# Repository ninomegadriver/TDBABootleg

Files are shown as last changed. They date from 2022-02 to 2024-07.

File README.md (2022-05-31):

# Taito do Brasil Arcade Bootleg  
**Jamma arcade board based on the original "Fantastic" hardware by Taito do Brasil**  
Nino MegaDriver - nino@nino.com.br  
License GPL v3.0  
***************** 
## Main Features  

- ESP32 Wroom Devkit V1 which functions as CPU and graphics generator.  
- Two AY-3-9010 PSGs
- Serial data bus with three Atmega328p to handle controller inputs and driving the PSGs.  
- Audio mixing between PSGs and 2 DACs which can be activated via dip switches.    
  
**Actual Board Picture:**  
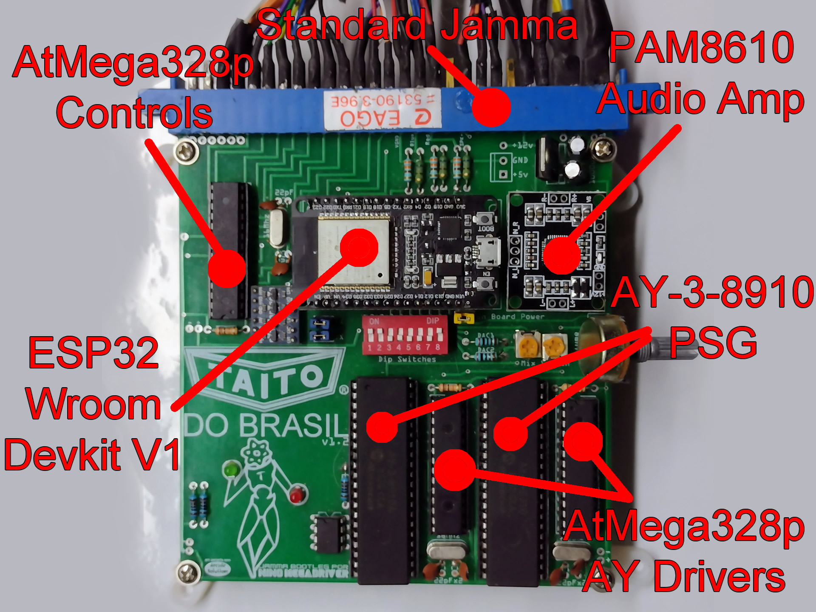
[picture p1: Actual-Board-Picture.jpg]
acual board picture
  
  
*****************
## PCB Gerbers  
**The board is released as "open hardware" under the GPL 3.0.  
[Gerbers for production is available here.](https://github.com/ninomegadriver/TDBABootleg/tree/main/PCB_Gerbers)**  
  
**PCB Footprints:**  
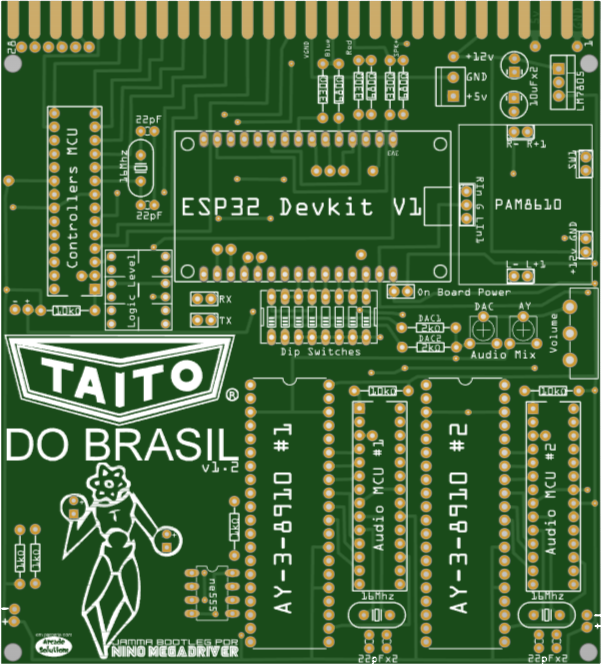
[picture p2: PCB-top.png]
PCB Top
  
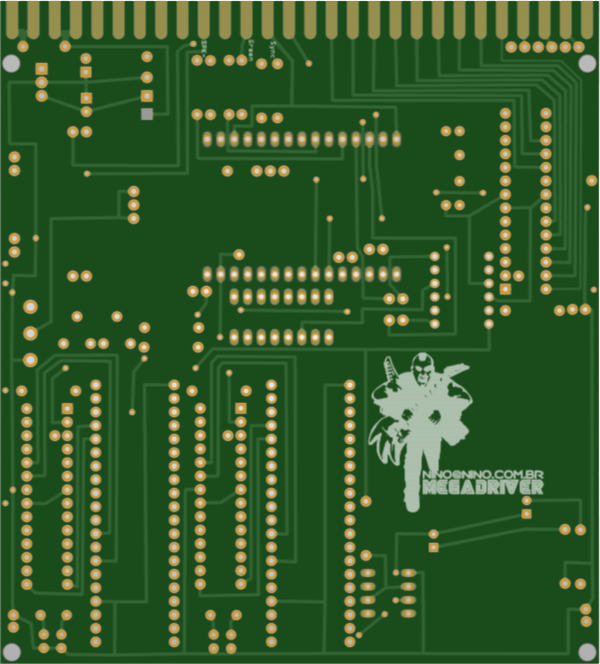
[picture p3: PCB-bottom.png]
PCB Bottom
  
  
***************
## Serial Protocol  
  
This project uses standard UART serial protocol at 115200 baud rate. One Atmega328p is used to poll player inputs and sends the data over serial. Two Atmega328p listens on serial for instructions to drive its own AY-3-8910 PSG.  

The controllers MCU sends two bytes, one for each player as follows:  
```
  0b00000001 => COIN;
  0b00000010 =>  START;
  0b00000100 =>  UP;
  0b00001000 =>  DOWN;
  0b00010000 =>  LEFT;
  0b00100000 =>  RIGHT;
  0b01000000 =>  BT1;
  0b10000000 =>  BT2;
```  
  
Each AY-3-8910 Atmega328p drivers has it's own #id hardcoded, data is sent as three bytes structured as:  
```
struct YMREG{
  uint8_t chip;
  uint8_t reg;
  uint8_t data;
  bool dirty = false;
};
(...)
      buf[0] = YMBUFF[ym_flush_pos].chip;
      buf[1] = YMBUFF[ym_flush_pos].reg;
      buf[2] = YMBUFF[ym_flush_pos].data;
      Serial.write(buf, 3);
      Serial.flush();
(...)
```  
The data is always received by the two drivers, but it's is only processed if it's flagged with its #id.  
  
***************************
## Supported Games  
  
This project was initially focused on the "Fantastic", an arcade "Galaxian" licensed game clone, developed by Taito do Brasil in 1981. It all started as a couple of spare boards donated to me. Later on, an original rack came in my shop for repair, providing me a real hardware to use as source of actual information. So, the initial goal was to run a Z80 emulator on an ESP32 but using original hardware for audio, the same configuration used on the Fantastic racks.  
  
As of today, we have the following fully playable games:  
- Fantastic, 1981.  
- Gorila, 1981.  
  
**See it in action here:**  
Taito Do Brasil Bootleg v1.2 - Fantastic Hardware (https://www.youtube.com/watch?v=sqsus4Gnz_k)  
  
The ESP32 should be powerful enough to run many more classic and single processed arcade games. A work-in-progress is ongoing for supporting more Taito do Brasil games that run on Space Invaders hardware, such as:  
  
- Galactica - Batalha Espacial.
- Indian Battle.
- Space Invaders.
- Space Invaders Part II.
- Polaris.
  
**Work-in-progress of the Invaders hardware here:**  
Taito Do Brasil Bootleg v1.2 - Invaders Hardware (WIP) (https://www.youtube.com/watch?v=LioPVbTkof8)  

***************************
## Special Thanks  
  
- Tom Walker and his emulator YAAME (http://yaame.emuunlim.com/) which served as a base for the graphics routines used in the [ESP32_HW_Fantastic](https://github.com/ninomegadriver/TDBABootleg/tree/main/ESP32_HW_Fantastic) code.
- Alessandro Scotti for his fast an reliable [Space Invaders emulator](https://walkofmind.com/programming/side/side.htm) which provided most of the routines used in the [ESP32_HW_Invaders](https://github.com/ninomegadriver/TDBABootleg/tree/main/ESP32_HW_Invaders) code.
- All MAME developers for providing tons of references and info in the MAME sources.  
- Fabrizio Di Vittorio for his amazing FabGL graphics library which made the video implementation in project really easy.  
- Alexsander dos Santos, which kindly donated a few Fantastic PCBs that served as a sparkling for this project. 
- Luis Culik from the "Museu do Pinball de Itu" for entrusting me a very rare and unique original Fantastic rack for repair, which also served as source of information on the actual original hardware.  
- Emerson de Holanda from "Arcade Solutions" for overall supporting the project.    
  
***************************
Comments, suggestions, support and help are always welcome.  
Wanna join in or just chat?  
You can reach me at:  
nino@nino.com.br  
[Facebook "ninomegadriver"](https://facebook.com/ninomegadriver)

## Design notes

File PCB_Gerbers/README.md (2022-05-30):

# "Taito do Brasil Arcade Bootleg v1.2" PCB  
## Gerbers provided as "open hardware" under the terms of GPL v3.0.  
  
PCB Top  
PCB Bottom  
  
**Bill Of Materials:**  
[Taito_do_Brasil_Arcade_Bootleg_v1.2_bom.html](https://github.com/ninomegadriver/TDBABootleg/blob/main/PCB_Gerbers/Taito_do_Brasil_Arcade_Bootleg_v1.2_bom.html)

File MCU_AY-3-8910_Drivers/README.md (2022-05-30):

# TDBABootleg: AY-3-8910 Drivers MCU  
Bin image for the ATmega328p used for driving the AY-3-8910 PSGs  
  
*****************************************
CHIP #1:  
  
Binary image:  
[MCU_AY-3-8910_AtMega328p-CHIP1.bin](https://github.com/ninomegadriver/TDBABootleg/raw/main/MCU_AY-3-8910_Drivers/MCU_AY-3-8910_AtMega328p-CHIP1.bin)  
  
Fuse configuration:  
Low byte: 0xFF  
High byte: 0xDE  
Extended: 0xFD  
Lock Byte: 0xCF  
  
Fuse reference screenshot:  
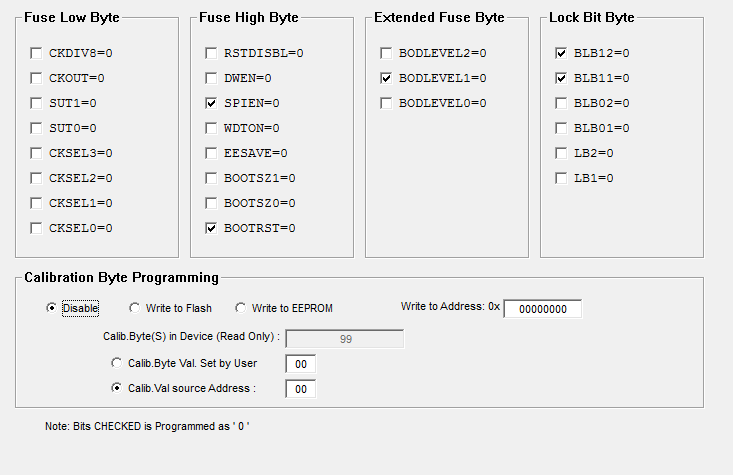
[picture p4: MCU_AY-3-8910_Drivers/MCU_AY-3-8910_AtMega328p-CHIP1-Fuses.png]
Atmega328p %1
  
  
****************************************  
CHIP #2:  
  
Binary dump:  
[MCU_AY-3-8910_AtMega328p-CHIP2.bin](https://github.com/ninomegadriver/TDBABootleg/raw/main/MCU_AY-3-8910_Drivers/MCU_AY-3-8910_AtMega328p-CHIP2.bin)  
  
Fuse configuration:  
Low byte: 0xFF  
High byte: 0xDE  
Extended: 0xFD  
Lock Byte: 0xFF  
  
Fuse reference screenshot:  
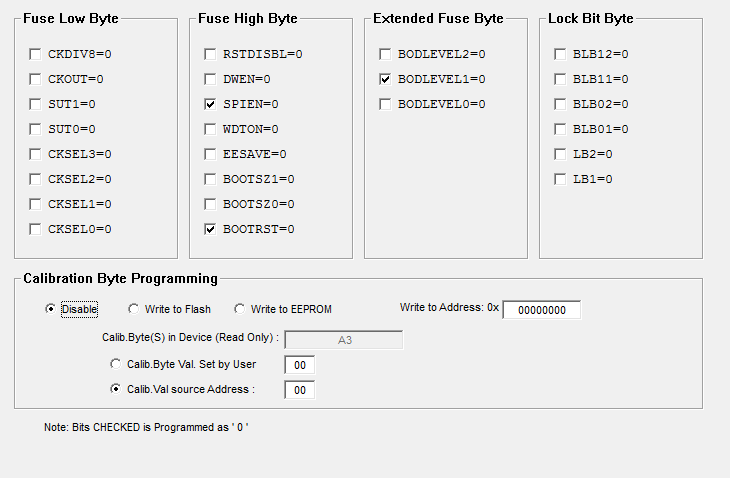
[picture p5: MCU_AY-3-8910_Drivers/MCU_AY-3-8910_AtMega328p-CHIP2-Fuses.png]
Atmega328p %1


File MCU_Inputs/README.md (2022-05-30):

# TDBABootleg: Player Inputs MCU  
Bin image for the ATmega328p used for handling the player inputs over jamma.  
  
Binary dump file:
[MCU_Inputs-ATMEGA328P.bin](https://github.com/ninomegadriver/TDBABootleg/raw/main/MCU_Inputs/MCU_Inputs-ATMEGA328P.bin)

Fuse configuration:  
Low byte: 0xFF  
High byte: 0xDE  
Extended: 0xFD  
Lock Byte: 0xFF  
  
Fuse reference configuration:  
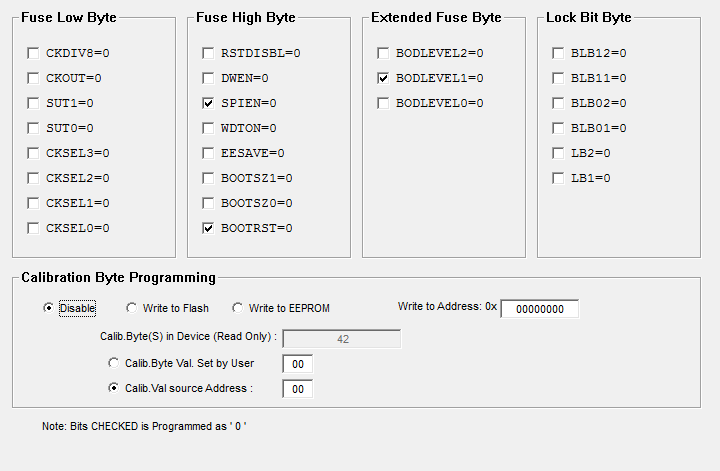
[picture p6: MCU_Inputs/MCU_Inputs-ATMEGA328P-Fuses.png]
Fuses Input MCU


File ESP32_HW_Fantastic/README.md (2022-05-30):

# TDBABootleg: Main code for the "FANTASTIC" Hardware  
  
Taito do Brasil Arcade Bootleg v1.2  
Nino MegaDriver - nino@nino.com.br  
License GPL v3.0  
  
Maincode for the ESP32 Devkit V1 module. Code based on the "FANTASTIC" arcade board manufactured by Taito do Brasil, which was itself based on the original Galaxian rack by Namco.  
  
Currently fully playable games:  
  
- Fantastic
- Gorila

Libraries used:  
  
- FabGL (http://www.fabglib.org/) for video generation.  
- DacAudio by https://www.xtronical.com/  
- Z80 emulator from Lin Ke-Fong.  
  
Special Thanks:  
  
- Tom Walker and his emulator YAAME (http://yaame.emuunlim.com/) which served as a base for the graphics routines used in this code.
- All MAME developers for providing tons of references and info in the MAME sources.  
- Fabrizio Di Vittorio for his amazing FabGL graphics library which made the video implementation in project really easy.  
- Alexsander dos Santos, which kindly donated a few Fantastic PCBs that served as a sparkling for this project. 
- Luis Culik from the "Museu do Pinball de Itu" for entrusting me a very rare and unique original Fantastic rack for repair, which also served as source of information on the actual original hardware.  
- Emerson de Holanda from "Arcade Solutions" for overall testing and supporting the project.  
  
Building Instructions:  
  
Download and install FabGL into your Arduino IDE and load the project. I strongly recommend modifying all FabGL sources to use the GCC "-O3" optimization flag as it will result on a huge increase of performance. On Linuxes, one suggestion is to enter the $/Arduino/libraries/FabGL folder and use "sed" to replace "-O2" with "-O3" like this:   
  
```
for i in `find -name "*.cpp"`; do sed -i 's/"O2"/"O3"/g' $i; done;
```  
  
I also recommend using this [sdkconfig](https://raw.githubusercontent.com/ninomegadriver/TDBABootleg/main/ESP32_HW_Fantastic/sdkconfig) with optimal settings for this project.  

See it in action here:  
Taito Do Brasil Bootleg v1.2 - Fantastic Hardware (https://www.youtube.com/watch?v=sqsus4Gnz_k)

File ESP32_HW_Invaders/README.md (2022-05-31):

# TDBABootleg: Main code for the "INVADERS" Hardware  
  
Taito do Brasil Arcade Bootleg v1.2  
Nino MegaDriver - nino@nino.com.br  
License GPL v3.0  
  
Maincode for the ESP32 Devkit V1 module. Code based on the "Space Invaders" arcade board manufactured by Taito do Brasil  
  
Most of this code was ported from the very fast and reliable emulator
["SIDE - Space Invaders Didactic Emulator"](https://walkofmind.com/programming/side/side.htm) by Alessandro Scotti.  
  
This is still in a work-in-progress state. However we have this currently playable games:  
  
- Galactica - Batalha Espacial.
- Indian Battle.
- Space Invaders.
- Space Invaders Part II.
- Polaris
  
Libraries used:  
  
- FabGL (http://www.fabglib.org/) for video generation.  
- DacAudio by https://www.xtronical.com/  
  
Special Thanks:  
  
- Alessandro Scotti for his fast an reliable Space Invaders emulator which provided most of the routines used here.
- All MAME developers for providing tons of references and info in the MAME sources.  
- Fabrizio Di Vittorio for his amazing FabGL graphics library which made the video implementation in project really easy.  
- Emerson de Holanda from "Arcade Solutions" for overall testing and supporting the project.  
  
Building Instructions:  
  
I strogly recommend using this [sdkconfig](https://raw.githubusercontent.com/ninomegadriver/TDBABootleg/main/ESP32_HW_Fantastic/sdkconfig) with optimal settings for this project.  

See a WIP video here:  
Taito Do Brasil Bootleg v1.2 - Invaders Hardware (WIP) (https://www.youtube.com/watch?v=LioPVbTkof8)

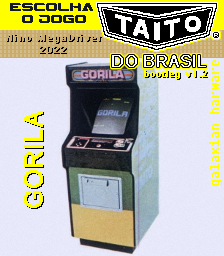
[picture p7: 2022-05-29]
ESP32_HW_Fantastic/resources/catalog.fw.png

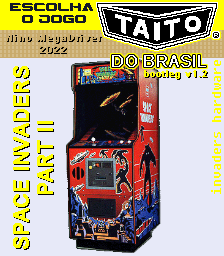
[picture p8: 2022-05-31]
ESP32_HW_Invaders/resources/catalog.fw.png

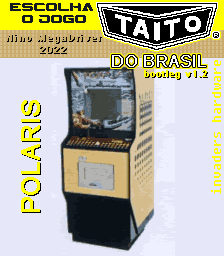
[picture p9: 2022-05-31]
ESP32_HW_Invaders/resources/bkp/menu_polaris.png

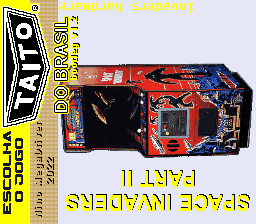
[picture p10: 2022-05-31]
ESP32_HW_Invaders/resources/menu_invaders2.png

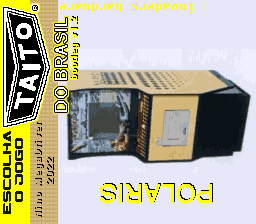
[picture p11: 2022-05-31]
ESP32_HW_Invaders/resources/menu_polaris.png

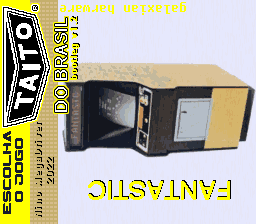
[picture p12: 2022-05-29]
ESP32_HW_Fantastic/resources/menu_fantastc.png

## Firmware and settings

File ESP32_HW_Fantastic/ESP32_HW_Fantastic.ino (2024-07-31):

#pragma GCC optimize ("O3")

/*
 * Taito do Brasil Arcade Bootleg v1.2
 * Nino MegaDriver - nino@nino.com.br
 * License GPL v3.0
 * 
 * Maincode for the ESP32 Devkit V1 module
 * Code based on the "FANTASTIC" arcade board
 * 
 * Libraries and Helpers used:
 * 
 * FabGL (http://www.fabglib.org/) for video generation
 * DacAudio by https://www.xtronical.com/
 * Z80 emulator code derived from Lin Ke-Fong
 * Graphics routines derived from YAAME by Tom Walker (http://yaame.emuunlim.com/)
 * +Tons of references and info taken from MAME sources
 * 
 */

// TIMER Helpers - used in Serial Tasks
#include "soc/timer_group_struct.h"
#include "soc/timer_group_reg.h"

// Usually sprite priority would not be needed as long as we
// clear the screen prior to start drawing on it. However we're not
// fast enought to fill the whole screen each frame, nor do we
// have enough RAM to use double buffering. So to avoid
// blinking sprites, we need to implement a priority system so
// not to draw the same pixel twice.
//
// Althought a boolean variable suggests that only one bit is
// necessary to store it, it is surprisingly stored as one whole byte!
//
// Then, if you think of a 256x256 pixels wide screen, it would
// take 65kb of RAM to store it into a variable and we obviously can't
// afford that... 
//
// However, if we treat each pixel as a single bit instead
// of one byte, the amount of RAM would go down to just 8k!
// 

byte objdirty[8192]; // 8192 bytes = 256*256/8, more then enought for us...
uint8_t busy = 0; // Semaphore for Video Drawing

// Core Configuration
int cpuCore  = 1; // Core # for CPU
int gfxCore  = 0; // Core # for GPU

// Bitwise heler functions defines
#define BITS_PER_BYTE (8)
#define GET_BIT(x, n) ((((x)[(n) / BITS_PER_BYTE]) & (0x1 << ((n) % BITS_PER_BYTE))) != 0)
#define SET_BIT(x, n) ((x)[(n) / BITS_PER_BYTE]) |= (0x1 << ((n) % BITS_PER_BYTE))
#define RESET_BIT(x, n) ((x)[(n) / BITS_PER_BYTE]) &= ~(0x1 << ((n) % BITS_PER_BYTE))

// Set a pixel at given position dirty
void set_dirty(int x, int y){
  int pixel = x * 256 + y;
  SET_BIT(objdirty,pixel);
}

// Reset dirty state of a pixel at given position
void reset_dirty(int x, int y){
  int pixel = x * 256 + y;
  RESET_BIT(objdirty,pixel);
}


// Return if pixel at given position is dirty
int get_dirty(int x, int y){
  int pixel = x * 256 + y;
  return GET_BIT(objdirty,pixel);
}

// Basic structure for transfering AY-3-8910
// register values over Serial
struct YMREG{
  uint8_t chip;
  uint8_t reg;
  uint8_t data;
  bool dirty = false;
};
#define YMBUFFSIZE 200                            // AY-3-8910 serial buffer transfer value
YMREG YMBUFF[YMBUFFSIZE];                         // AY-3-8910 buffer
uint8_t ym_flush_pos = 0;                         // AY-3-8910 flush position
uint8_t ym_write_pos = 0;                         // AY-3-8910 write position

#include "fabgl.h"                                // Main FabGL include
#include "machine.h"                              // Z80 Machine object
#include "res.hpp"

uint8_t player1_ctl = 0x00;                       // Byte containing the players buffer
uint8_t player2_ctl = 0x00;                       // One bit for each input

int GAME = 7;                                     // What game are we running today? See numbering bellow...


// INPUT BITS for each game supported
// Currently only Fantastic and Kong/Gorila are fully playable
//
// Game                            [Fantastic], [Kong], [Time Fighters], [Super Star Crest], [Zig Zag], [Galaxian Taito], [Munch Man], [Galaxy Empire]
// Index                                0         1            2                3                 4            5               6              7
uint8_t IPT_COIN1[] =           {     0x02,     0x02,        0x02,             0x01,            0x01,         0x02,           0x02,         0x02,  };
uint8_t IPT_JOYSTICK_LEFT[] =   {     0x04,     0x04,        0x04,             0x04,            0x04,         0x04,           0x04,         0x02,  };
uint8_t IPT_JOYSTICK_RIGHT[] =  {     0x08,     0x08,        0x08,             0x08,            0x08,         0x08,           0x08,         0x02,  };
uint8_t IPT_JOYSTICK_UP[] =     {     0x07,     0x80,        0x80,             0x07,            0x20,         0x07,           0x40,         0x02,  };
uint8_t IPT_JOYSTICK_DOWN[] =   {     0x07,     0x20,        0x20,             0x07,            0x40,         0x07,           0x80,         0x02,  };
uint8_t IPT_BUTTON1[] =         {     0x10,     0x07,        0x10,             0x10,            0x10,         0x10,           0x10,         0x02,  };
uint8_t IPT_START1[] =          {     0x01,     0x01,        0x01,             0x01,            0x01,         0x01,           0x01,         0x02,  };
uint8_t IPT_START2[] =          {     0x02,     0x02,        0x02,             0x02,            0x02,         0x02,           0x02,         0x02,  };

// Frame Duration time.
// Tune in if you want more fps
uint64_t frame_time[] =         {     14000,     140000,       14000,            14000,           14000,         14000,        14000,       14000   };

int nmi = 0;                                      // MNI Helper, 1 when MNI is pending

fabgl::VGAController  DisplayController;          // Main Video Object
fabgl::Canvas cv(&DisplayController);

Machine              fantastc;                    // Main CPU machine object

#include "XT_DAC_Audio.h"                         // DacAudio main include
XT_DAC_Audio_Class DacAudio(25,0);                // Main Class, using GPIO25 as PCM generator
int voice_playing[] = {0, 0, 0, 0, 0, 0 , 0};     // Helper for controlling voice samples
long voice_latch = 0;                             // Latch for voice samples

int screen_width   = 0;                           // Main output screen width, overwrited on setup();
int screen_height  = 0;                           // Main output screen height, overwrited on setup();

bool wireframe     = false;                       // Draw wireframe to display screen bounds?

uint8_t pixel[32];                                // R/W array of "pixels with defined color", used as the color palette
#include "fantastc.hpp"                           // "FANTASTIC" game includes
#include "kong.hpp"                               // "GORILA" (a.k.a "kong") game includes
#include "timefgtr.hpp"                           // "TIME FIGHTER" game includes
#include "sstarcrs.hpp"                           // "SUPER STAR CREST" game includes
#include "zigzag.hpp"                             // "ZIG ZAG" game includes
#include "samples.hpp"                            // PCM samples used by "GORILA"
#include "munch.hpp"                              // "Munch Man" game includes
#include "galaxiant.hpp"                          // "Galaxian Title" game includes"
#include "galemp.hpp"

// Menuing Vars
Bitmap *menu_bitmaps[] = { &menu_fantastc, &menu_kong};                 // Bitmaps for the selection page for each game
XT_Wav_Class *menu_samples[] = {&wav_menu_fantastic, &wav_menu_gorila}; // Samples for each menu page
uint8_t menu_active = 0;                                                // Menu active?
int menu_item = GAME;                                                   // Default menu item pointing to default GAME
uint8_t menu_item_last = -1;                                            // Last selected item
uint8_t menu_item_max = 1;                                              // Max index for the menu items (Currently only Fantastic and Kong are playable


// Direct sets a pixel on the output screen buffer
bool setpixel(int x=0, int y=0, int idx=0 , int force = 0){

    if(get_dirty(x, y) && force == 0) {
      reset_dirty(x, y);
      return false; // If pixel is dirty/already drawn, skip it!
    }

    if(idx>31) idx=0;
    int dx = screen_width-y-1;
    int dy = x;

    dx-=32;
    dy-=16;
    if(dx<32 || dx > 288 || dy<3 || dy > screen_height-2) return false;

    // Let's fix the orientation again to match original hardware
    dx = screen_width  - dx;
    dy = screen_height - dy;
    

    if(dx < screen_width && dy <screen_height && dx>= 0 && dy >= 0){
        DisplayController.setRawPixel(dx,dy,pixel[idx]);
        return true;
    }else{
       return false;
    }
}

// Very ugly but somehow needled.
// Using pointers to complex arrays panics or slows the esp32 core
int tileval(int c, int x, int y){
  if(GAME == 0) return fantastc_tiles[c][x][y];
  if(GAME == 1) return kong_tiles[c][x][y];
  if(GAME == 2) return timefgtr_tiles[c][x][y];
  if(GAME == 3) return crest_tiles[c][x][y];
  if(GAME == 4) return zigzag_tiles[c][x][y];
  if(GAME == 5) return galaxiant_tiles[c][x][y];
  if(GAME == 6) return munch_tiles[c][x][y];
  if(GAME == 7) return galemp_tiles[c][x][y];
  return 0;
}

// Helper, prints a tile on screen
// Using for debugging
void tilep(int t, int xx, int yy, int tint=0, int xflip=0, int yflip=0, int bits=0){
  int idx;
  for(int x=0;x<8;x++){
    for(int y=0;y<8;y++){
      idx =  tileval(t,x,y);
      setpixel(x+xx, y+yy, idx);
    }
  }
}

// Helper, prints all tiles on screen
// Using for debugging
void dumptiles(){
  int xx = 0;
  int yy = 0;
  for(int c=0; c<512; c++)
  {
    tilep(c, xx, yy);
    xx+=10;
    if(xx>256){
      xx = 0;
      yy+=10;
      if(yy>256){
        yy = 0;
      }
    }
  }  
}


// Code derived from YAAME by Tom Walker (http://yaame.emuunlim.com/)
// Draws a decoded tile on screen
void drawtilenew(int tile, int x, int y, int col, int xflip, int yflip, int bits)
{

        int xx,yy, idx;
        if (!yflip)
        {
               if (!xflip)
               {
                        for (yy=0;yy<8;yy++)
                            for (xx=0;xx<8;xx++){
                                  idx = tileval(tile,xx,yy)|(col<<bits);
                                  setpixel(x+xx, y+yy, idx);
                            }
                                
               }
               else
               {
                        for (yy=0;yy<8;yy++)
                            for (xx=0;xx<8;xx++){
                                  idx = tileval(tile,7-xx,yy)|(col<<bits);
                                  setpixel(x+xx, y+yy, idx);
                            }
               
               }
        }
        else
        {
               if (!xflip)
               {
                        for (yy=0;yy<8;yy++)
                            for (xx=0;xx<8;xx++){
                                  idx = tileval(tile,xx,7-yy)|(col<<bits);
                                  setpixel(x+xx, y+yy, idx);
                            }
                                
               }
               else
               {
                        for (yy=0;yy<8;yy++)
                            for (xx=0;xx<8;xx++){
                                  idx = tileval(tile,7-xx,7-yy)|(col<<bits);
                                  setpixel(x+xx, y+yy, idx);
                            }
                                
               }
        }
}
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
void loop() {
  cpuCore = xPortGetCoreID();
  if(cpuCore == 1) gfxCore = 0;
  else gfxCore = 1;
  load_game(GAME);
}


/*
 * Z80 Machine Declarations
 */
Machine::Machine()
  : m_realSpeed(false)
{
  m_Z80.setCallbacks(this, readByte, writeByte, readWord, writeWord, readIO, writeIO);
}

Machine::~Machine()
{
  delete [] m_RAM;
}

// Title screen includes substitution for "GORILLA"
#include "gorila_title.hpp"                       

bool chkSprite(int x, int y){
  int spritex,spritey,cc,ccc;
  for (cc=14;cc>-1;cc--){
    ccc=cc<<2;
    spritex=fantastc.m_RAM[0x9840+ccc]+8;
    if (spritex>8 && spritex<0xF8){
      spritey=fantastc.m_RAM[0x9843+ccc]+1;
      if(x == spritex && y == spritey) return false;
      else return true;
    }
  }
}

void drawBullets(const uint8_t *base){
  int dx, dy;
  int m_flipscreen_y = 0;
  /* iterate over scanlines */
  for (int y = 0; y <= 224; y++)
  {
    uint8_t shell = 0xff, missile = 0xff;
    uint8_t effy;

    /* the first 3 entries match Y-1 */
    effy = m_flipscreen_y ? ((y - 1) ^ 255) : (y - 1);
    for (int which = 0; which < 3; which++)
      if (uint8_t(base[which*4+1] + effy) == 0xff)
        shell = which;

    /* remaining entries match Y */
    effy = m_flipscreen_y ? (y ^ 255) : y;
    for (int which = 3; which < 8; which++)
      if (uint8_t(base[which*4+1] + effy) == 0xff)
      {
        if (which != 7)
          shell = which;
        else
          missile = which;
      }
    
    /* draw the shell */
    if (shell != 0xff) {
      dy = 224 - base[shell*4+3] + 24 ;
      dx = 255 -y + 8;
      setpixel(dx, dy,   3, 32);
      setpixel(dx, dy+1, 3, 32);
      setpixel(dx, dy+2, 3, 32);
    }

    if (missile != 0xff){
      dy = 224 - base[missile*4+3] + 24;
      dx = 255 -y + 8;
      setpixel(dx, dy,   3, 1);
      setpixel(dx, dy+1, 3, 1);
      setpixel(dx, dy+2, 3, 1);
    }
    
  }
}

// Main game graphics processing routine
void Machine::draw(){
  busy = 1; // Take the drawing slot
  int y,x, destx, desty, cc, ccc, spritebase, videobase;
  int pos=0;
  unsigned char c;
  signed char scroll;
  int kong_title=0;
  int kong_tente=0;

  if(wireframe == true) screen_bounds(); // Draw screen boundaries frame
  if(GAME == 4 || GAME == 5 || GAME == 6 || GAME == 7){
    spritebase = 0x5800;
    videobase  = 0x5000;
  }else{
    spritebase = 0x9800;
    videobase  = 0x9000;
  }

  // Sprites processing, for all games
  int spritex,spritey,spritecode,xflip,yflip,spritecol;
        for (cc=14;cc>-1;cc--)
        {
          ccc=cc<<2;
          spritex=fantastc.m_RAM[spritebase+0x40+ccc]+8;
          
          if (spritex>8 && spritex<0xF8){
            spritey=fantastc.m_RAM[spritebase+0x43+ccc]+1;
            spritecol=fantastc.m_RAM[spritebase+0x42+ccc]&7;
            spritecode=fantastc.m_RAM[spritebase+0x41+ccc]&0x3F;
            spritecode<<=2;
            if(GAME == 4 || GAME == 6) spritecode+=256;
            if(GAME == 0 || GAME == 1) spritecode += 0x100;
            if(spritecode == 408) kong_tente++;                    // THIS IS A HACK! Condition to invoke "Tente outra vez" sample for "GORILA"
            xflip=fantastc.m_RAM[spritebase+0x41+ccc]&0x80;
            yflip=fantastc.m_RAM[spritebase+0x41+ccc]&0x40;
                        if (!xflip)
                        {
                                if (!yflip)
                                {
                                        drawtilemasknew(spritecode+2,spritex,spritey,spritecol,0,0,2);
                                        drawtilemasknew(spritecode,spritex+8,spritey,spritecol,0,0,2);
                                        drawtilemasknew(spritecode+3,spritex,spritey+8,spritecol,0,0,2);
                                        drawtilemasknew(spritecode+1,spritex+8,spritey+8,spritecol,0,0,2);
                                }
                                else
                                {
                                        drawtilemasknew(spritecode+2,spritex,spritey+8,spritecol,0,1,2);
                                        drawtilemasknew(spritecode,spritex+8,spritey+8,spritecol,0,1,2);
                                        drawtilemasknew(spritecode+3,spritex,spritey,spritecol,0,1,2);
                                        drawtilemasknew(spritecode+1,spritex+8,spritey,spritecol,0,1,2);
                                }
                        }
                        else
                        {
                                if (!yflip)
                                {
                                        drawtilemasknew(spritecode+2,spritex+8,spritey,spritecol,1,0,2);
                                        drawtilemasknew(spritecode,spritex,spritey,spritecol,1,0,2);
                                        drawtilemasknew(spritecode+3,spritex+8,spritey+8,spritecol,1,0,2);
                                        drawtilemasknew(spritecode+1,spritex,spritey+8,spritecol,1,0,2);
                                }
                                else
                                {
                                        drawtilemasknew(spritecode+2,spritex+8,spritey+8,spritecol,1,1,2);
                                        drawtilemasknew(spritecode,spritex,spritey+8,spritecol,1,1,2);
                                        drawtilemasknew(spritecode+3,spritex+8,spritey,spritecol,1,1,2);
                                        drawtilemasknew(spritecode+1,spritex,spritey,spritecol,1,1,2);
                                }
                        }
          }
          
        }


  // Background Processing, for all games
  for (x = 32; x>0; x--)
  {
    for (y = 0; y < 32; y++)
    {
        c = fantastc.m_RAM[videobase+(pos++)];
        //if(c == 0x10) continue;
        if(c == 176)  kong_title++;
        scroll=(signed char)fantastc.m_RAM[spritebase+(y<<1)];
        destx = ((x<<3)+scroll)&255;
        desty = y<<3;
        // THIS IS A HACK!
        // Specific conditions for detecting the title screen of "GORILA"
        if(GAME == 1 && fantastc.m_Z80.readRegByte(18) == 0 && fantastc.m_Z80.readRegByte(8) == 167 && desty >= 80 && desty <= 176) {
          // Ignore these tiles, this space will be filled bellow
        } else drawtilenew(c,destx,desty,fantastc.m_RAM[spritebase+0x01+(y<<1)],0,0,2); // Otherwise just draw those tiles
    }
  }


  // THIS IS A HACK!
  // Ok, so it's the title screen of "GORILA", let's replace that logo with the correct one!
  if(GAME == 1 && fantastc.m_Z80.readRegByte(18) == 0 && fantastc.m_Z80.readRegByte(8) == 167 && kong_title == 65) gorila_title();


  if(GAME == 7){
    drawBullets(&fantastc.m_RAM[0x5800+96]);
  }

  // bullets processing, used by "FANTASTIC" and "TIME FIGHTERS"
  if(GAME == 0 || GAME == 2 || GAME == 5){
    for (cc=0;cc<32;cc+=4)
    {
      if(GAME == 1){
        x=fantastc.m_RAM[spritebase+(0xc1+cc)]+7;
        y=256-fantastc.m_RAM[spritebase+(0xc3+cc)]-4;
      }else{
        x=fantastc.m_RAM[0x5861+cc];
        y=256-fantastc.m_RAM[0x5863+cc]-4;
      }
      if (x>0&&x<256&&y>-1&&y<253)
      {
        if (cc!=28)
        {
            setpixel(x, y, 3);
            setpixel(x, y+1, 3);
            setpixel(x, y+2, 3);
         }
         else
         {
            setpixel(x+8, y, 7);
            setpixel(x+8, y+1, 7);
            setpixel(x+8, y+2, 7);
          }
      }
    }
  }



  // PCM Samples processings for "GORILA"
  if(GAME == 1){
    if(kong_tente > 0)                                     // Should we play "Tente outra vez"?
    {
      if(voice_playing[3] == 0){
        DacAudio.Play(&wav_tente);
        voice_playing[3] = 1;
      }
    }else if(kong_tente == 0){
      voice_playing[3] = 0;
    }
    if(kong_title == 65 && voice_playing[0] == 0){         // Sould we play "Eu sou o GORILA"?
      DacAudio.StopAllSounds();
      DacAudio.Play(&wav_gorila);
      voice_playing[0] = 1;
    }else if(kong_title == 0){
      voice_playing[0] = 0;
    }
    if(fantastc.m_RAM[videobase+(160)] == 0x60){
      if(voice_playing[1] == 0){
        DacAudio.Play(&wav_venha);
        voice_playing[1] = 1;
      }
    }else{
      voice_playing[1] = 0;
    }
    DacAudio.FillBuffer();
  }

  busy = 0; // Free drawing slot
  
}

// Paralell task for the graphics generation on core1
void drawTASK( void * pvParameters ){
  fantastc.draw();
  vTaskDelete(NULL);
}

// Loads a buffer into the Z80 emulator RAM
void Machine::load(int address, uint8_t const * data, int length)
{
  for (int i = 0; i < length; ++i)
    m_RAM[address + i] = data[i];
}

// Creates a RAM object for the Z80 emulator
void Machine::attachRAM(int RAMSize)
{
  m_RAM = new uint8_t[RAMSize];
}

// Steps the Z80 CPU
int Machine::nextStep()
{
  return m_Z80.step();
}
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

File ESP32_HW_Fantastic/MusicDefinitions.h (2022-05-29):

/*************************************************
 * Public Constants - XT_Dac_Audio (not used yet)
 *************************************************/


// Notes and frequencies, see after this for an array of bytes that reference these values
// although this may seem wasteful in memory, when it comes to adding background music we would
// have to have arrays of 2 bytes for the frequencies, but instead we can have an array of single
// bytes that represent the notes as there are less than 256 of them. 


#define FNOTE_B0  31
#define FNOTE_C1  33
#define FNOTE_CS1 35
#define FNOTE_D1  37
#define FNOTE_DS1 39
#define FNOTE_E1  41
#define FNOTE_F1  44
#define FNOTE_FS1 46
#define FNOTE_G1  49
#define FNOTE_GS1 52
#define FNOTE_A1  55
#define FNOTE_AS1 58
#define FNOTE_B1  62
#define FNOTE_C2  65
#define FNOTE_CS2 69
#define FNOTE_D2  73
#define FNOTE_DS2 78
#define FNOTE_E2  82
#define FNOTE_F2  87
#define FNOTE_FS2 93
#define FNOTE_G2  98
#define FNOTE_GS2 104
#define FNOTE_A2  110
#define FNOTE_AS2 117
#define FNOTE_B2  123
#define FNOTE_C3  131
#define FNOTE_CS3 139
#define FNOTE_D3  147
#define FNOTE_DS3 156
#define FNOTE_E3  165
#define FNOTE_F3  175
#define FNOTE_FS3 185
#define FNOTE_G3  196
#define FNOTE_GS3 208
#define FNOTE_A3  220
#define FNOTE_AS3 233
#define FNOTE_B3  247
#define FNOTE_C4  262
#define FNOTE_CS4 277
#define FNOTE_D4  294
#define FNOTE_DS4 311
#define FNOTE_E4  330
#define FNOTE_F4  349
#define FNOTE_FS4 370
#define FNOTE_G4  392
#define FNOTE_GS4 415
#define FNOTE_A4  440    
#define FNOTE_AS4 466
#define FNOTE_B4  494
#define FNOTE_C5  523
#define FNOTE_CS5 554
#define FNOTE_D5  587
#define FNOTE_DS5 622
#define FNOTE_E5  659
#define FNOTE_F5  698
#define FNOTE_FS5 740
#define FNOTE_G5  784   
#define FNOTE_GS5 831
#define FNOTE_A5  880
#define FNOTE_AS5 932
#define FNOTE_B5  988
#define FNOTE_C6  1047	
#define FNOTE_CS6 1109
#define FNOTE_D6  1175
#define FNOTE_DS6 1245
#define FNOTE_E6  1319
#define FNOTE_F6  1397
#define FNOTE_FS6 1480
#define FNOTE_G6  1568
#define FNOTE_GS6 1661
#define FNOTE_A6  1760
#define FNOTE_AS6 1865
#define FNOTE_B6  1976
#define FNOTE_C7  2093
#define FNOTE_CS7 2217
#define FNOTE_D7  2349
#define FNOTE_DS7 2489
#define FNOTE_E7  2637
#define FNOTE_F7  2794
#define FNOTE_FS7 2960
#define FNOTE_G7  3136
#define FNOTE_GS7 3322
#define FNOTE_A7  3520
#define FNOTE_AS7 3729
#define FNOTE_B7  3951
#define FNOTE_C8  4186
#define FNOTE_CS8 4435
#define FNOTE_D8  4699
#define FNOTE_DS8 4978


// These notes index the above in the array (after removal of negative sign)
#define NOTE_SILENCE 0
#define NOTE_B0  -1
#define NOTE_C1  -2
#define NOTE_CS1 -3
#define NOTE_D1  -4
#define NOTE_DS1 -5
#define NOTE_E1  -6
#define NOTE_F1  -7
#define NOTE_FS1 -8
#define NOTE_G1  -9
#define NOTE_GS1 -10
#define NOTE_A1  -11
#define NOTE_AS1 -12
#define NOTE_B1  -13
#define NOTE_C2  -14
#define NOTE_CS2 -15
#define NOTE_D2  -16
#define NOTE_DS2 -17
#define NOTE_E2  -18
#define NOTE_F2  -19
#define NOTE_FS2 -20
#define NOTE_G2  -21
#define NOTE_GS2 -22
#define NOTE_A2  -23
#define NOTE_AS2 -24
#define NOTE_B2  -25
#define NOTE_C3  -26
#define NOTE_CS3 -27
#define NOTE_D3  -28
#define NOTE_DS3 -29
#define NOTE_E3  -30
#define NOTE_F3  -31
#define NOTE_FS3 -32
#define NOTE_G3  -33
#define NOTE_GS3 -34
#define NOTE_A3  -35
#define NOTE_AS3 -36
#define NOTE_B3  -37
#define NOTE_C4  -38
#define NOTE_CS4 -39
#define NOTE_D4  -40
#define NOTE_DS4 -41
#define NOTE_E4  -42
#define NOTE_F4  -43
#define NOTE_FS4 -44
#define NOTE_G4  -45
#define NOTE_GS4 -46
#define NOTE_A4  -47
#define NOTE_AS4 -48
#define NOTE_B4  -49
#define NOTE_C5  -50
#define NOTE_CS5 -51
#define NOTE_D5  -52
#define NOTE_DS5 -53
#define NOTE_E5  -54
#define NOTE_F5  -55
#define NOTE_FS5 -56
#define NOTE_G5  -57
#define NOTE_GS5 -58
#define NOTE_A5  -59
#define NOTE_AS5 -60
#define NOTE_B5  -61
#define NOTE_C6  -62
#define NOTE_CS6 -63
#define NOTE_D6  -64
#define NOTE_DS6 -65
#define NOTE_E6  -66
#define NOTE_F6  -67
#define NOTE_FS6 -68
#define NOTE_G6  -69
#define NOTE_GS6 -70
#define NOTE_A6  -71
#define NOTE_AS6 -72
#define NOTE_B6  -73
#define NOTE_C7  -74
#define NOTE_CS7 -75
#define NOTE_D7  -76
#define NOTE_DS7 -77
#define NOTE_E7  -78
#define NOTE_F7  -79
#define NOTE_FS7 -80
#define NOTE_G7  -81
#define NOTE_GS7 -82
#define NOTE_A7  -83
#define NOTE_AS7 -84
#define NOTE_B7  -85
#define NOTE_C8  -86
#define NOTE_CS8 -87
#define NOTE_D8  -88
#define NOTE_DS8 -89
#define SCORE_END -127


// Tempos in BPM
#define TEMPO_LARGHISSIMO 20 
#define TEMPO_GRAVE 30
#define TEMPO_LARGO 40
#define TEMPO_LENTO 50
#define TEMPO_LARGHETTO 60
#define TEMPO_ADAGIO  70
#define TEMPO_ADAGIETTO 77
#define TEMPO_ADENTE 84
#define TEMPO_ANDANTINO 92
#define TEMPO_MARCIA_MODERATO 100
#define TEMPO_ANDANTE_MODERATO 110
#define TEMPO_MODERATO 120
#define TEMPO_ALLEGRO 156
#define TEMPO_PRESTO 200
#define TEMPO_PRESTISSIMO 300
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

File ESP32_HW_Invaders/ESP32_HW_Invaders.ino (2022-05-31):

#pragma GCC optimize ("O3")

/*
 * Taito do Brasil Arcade Bootleg v1.2
 * Nino MegaDriver - nino@nino.com.br
 * License GPL v3.0
 * 
 * Maincode for the ESP32 Devkit V1 module
 * based on the Space Invaders arcade board
 * 
 * Most of this code was ported from the very fast and reliable
 * emulator "SIDE - Space Invaders Didactic Emulator" by Alessandro Scotti.
 * (https://walkofmind.com/programming/side/side.htm)
 * 
 * Libraries and Helpers used:
 * 
 * FabGL (http://www.fabglib.org/) for video generation
 * DacAudio by https://www.xtronical.com/
 * 
 */

// START: Initial Includes & Declares
#include "soc/timer_group_struct.h"
#include "soc/timer_group_reg.h"
int scanLineColor[260];
float fps = 59.541985;
long cycles_per_interrupt = (1996800 / (2*fps));
uint8_t pixel[6];
// END: Initial Includes & Declares

// START: JammaSerialController
uint8_t player1_ctl = 0x00;
uint8_t player2_ctl = 0x00;
bool getBit(unsigned char byte, int position) // position in range 0-7
{
    return (byte >> position) & 0x1;
}
void SerialTASK( void * pvParameters ){
  uint8_t ctl[2];
  while(1){
    TIMERG0.wdt_wprotect=TIMG_WDT_WKEY_VALUE;
    TIMERG0.wdt_feed=1;
    TIMERG0.wdt_wprotect=0;
    if (Serial.available() > 0) {
      Serial.readBytes(ctl, 2);
      player1_ctl = ctl[0];
      player2_ctl = ctl[1];
    }
    delayMicroseconds(10);
  }
  vTaskDelete(NULL);
}
// END: JammaSerialController

// START: Audio Libs & Routines
#include "XT_DAC_Audio.h"
XT_DAC_Audio_Class DacAudio(25,0);
void DACTask( void * pvParameters ){
  while(1){
    TIMERG0.wdt_wprotect=TIMG_WDT_WKEY_VALUE;
    TIMERG0.wdt_feed=1;
    TIMERG0.wdt_wprotect=0;
    DacAudio.FillBuffer();
    delayMicroseconds(1);
  }
  vTaskDelete(NULL);
}
#include "samples.hpp"
// END: // START: Audio Libs & Routines

// START: CPU Emulation Includes & Declares
extern "C" {
  #include "i8080.h"
}
uint8_t memory[65535];
i8080 cpu;
// END: CPU Emulation Includes & Declares


// START: Port & Button Events
static int      nShips  = 3;
static int      nEasy   = 0;
unsigned        sounds_;
unsigned char   port1_;
unsigned char   port2i_;    // Port 2 in
unsigned char   port2o_;    // Port 2 out
unsigned char   port3o_;    // Port 3 out
unsigned char   port4lo_;   // Port 4 out (lo)
unsigned char   port4hi_;   // Port 4 out (hi)
unsigned char   port5o_;    // Port 5 out
enum Events {
        KeyLeftDown     = 0,
        KeyLeftUp,
        KeyRightDown,
        KeyRightUp,
        KeyFireDown,
        KeyFireUp,
        KeyOnePlayerDown,
        KeyOnePlayerUp,
        KeyTwoPlayersDown,
        KeyTwoPlayersUp,
        CoinInserted
};
void fireEvent( int event )
{
    switch( event ) 
    {
    case KeyLeftDown:
        port1_ |= 0x20;
        break;
    case KeyLeftUp:
        port1_ &= ~0x20; 
        break;
    case KeyRightDown:
        port1_ |= 0x40; 
        break;
    case KeyRightUp:
        port1_ &= ~0x40; 
        break;
    case KeyFireDown:
        port1_ |= 0x10;
        break;
    case KeyFireUp:
        port1_ &= ~0x10;
        break;
    case KeyOnePlayerDown:
        port1_ |= 0x04;
        break;
    case KeyOnePlayerUp:
        port1_ &= ~0x04;
        break;
    case KeyTwoPlayersDown:
        port1_ |= 0x02;
        break;
    case KeyTwoPlayersUp:
        port1_ &= ~0x02;
        break;
    case CoinInserted:
        port1_ |= 0x01;
        break;
    }
}
static uint8_t generic_port_in(void* userdata, uint8_t port) {

  unsigned char   b = 0;

    switch( port ) {
    case 1: 
        b = port1_; 
        port1_ &= 0xFE; 
        break;
    case 2: 
        b = (port2i_ & 0x8F) | (port1_ & 0x70); // Player 1 keys are used for player 2 too
        break;
    case 3: 
        b = (unsigned char)((((port4hi_ << 8) | port4lo_) << port2o_) >> 8);
        break;
    }

    if( port == 1 || port == 2){
      if(getBit(player1_ctl,1) == false) fireEvent( KeyOnePlayerUp );  else fireEvent( KeyOnePlayerDown );
      if(getBit(player2_ctl,1) == false) fireEvent( KeyTwoPlayersUp ); else fireEvent( KeyTwoPlayersDown );
      if(getBit(player1_ctl,0) == false) fireEvent( CoinInserted );
      if(getBit(player1_ctl,4) == false) fireEvent( KeyLeftUp );       else fireEvent( KeyLeftDown );
      if(getBit(player1_ctl,5) == false) fireEvent( KeyRightUp );      else fireEvent( KeyRightDown );
      if(getBit(player1_ctl,6) == false) fireEvent( KeyFireUp );       else fireEvent( KeyFireDown );
    }

    return b;
  
}

static void generic_port_out(void* userdata, uint8_t addr, uint8_t b) {
    switch( addr ) {
    case 2:
        port2o_ = b;
        break;
    case 3:
        // Port 3 controls some sounds
        if( ! (b & 0x01) ) sounds_ &= ~SoundUfo;
        if( b & 0x01 ) {
          sounds_ |= SoundUfo;
          playSample(1);
        }
        if( (b & 0x02) && !(port3o_ & 0x02) ){
          sounds_ |= SoundShot;
          playSample(2);
        }
        if( (b & 0x04) && !(port3o_ & 0x04) ) {
          sounds_ |= SoundBaseHit;
          playSample(3);
        }
        if( (b & 0x08) && !(port3o_ & 0x08) ){
          sounds_ |= SoundInvaderHit;
          playSample(4);
        }
        port3o_ = b;
        break;
    case 4:
        port4lo_ = port4hi_;
        port4hi_ = b;
        break;
    case 5:
        // Port 5 controls some sounds
        
        if( (b & 0x01) && !(port5o_ & 0x01) ) { 
          sounds_ |= SoundWalk1;
          playSample(5);
        }
        if( (b & 0x02) && !(port5o_ & 0x02) ) {
          sounds_ |= SoundWalk2;
          playSample(6);
        }
        if( (b & 0x04) && !(port5o_ & 0x04) ) {
          sounds_ |= SoundWalk3;
          playSample(7);
        }
        if( (b & 0x08) && !(port5o_ & 0x08) ) {
          sounds_ |= SoundWalk4;
          playSample(8);
        }
        if( (b & 0x10) && !(port5o_ & 0x10) ) {
          sounds_ |= SoundUfoHit;
          playSample(9);
        }
        port5o_ = b;
        break;
    }
}
// END: Port & Button Events

// START: Game Includes
#include "galactic.hpp"
#include "invaders.hpp"
#include "polarisbr.hpp"
#include "invadpt2br.hpp"
#include "indianbtbr.hpp"
// END: Game Includes

uint8_t GAME = 0;

// START: Graphics Generic Screen & Declares
#include <fabgl.h>
#include "res.hpp"
fabgl::VGAController DisplayController;
fabgl::Canvas cv(&DisplayController);
int screen_width, screen_height;
void setpixel(int x, int y, int idx){
    int c = 0;
    if(idx > 0) c = scanLineColor[y];
    if(x <= 224 && y <=260 && x>= 0 && y >= 0){ // Primeira Verificação
        y+= 30;
        x+= 8;
        x = screen_height - x;
        y = screen_width - y;
        if(x<screen_height && y < screen_width && x>0 && y>0) DisplayController.setRawPixel(y, x, pixel[c]);
    }
}
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

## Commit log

2022-02-15 Delete ESP32HW_Fantastic directory
    Moved to a new name format
2022-05-29 updated to version 1.2
    [Taito_do_Brasil_Arcade_Bootleg_v1.2_contour.gm1, Taito_do_Brasil_Arcade_Bootleg_v1.2_copperBottom.gbl, Taito_do_Brasil_Arcade_Bootleg_v1.2_copperTop.gtl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]
2022-05-29 removed older 1.1v
    [Taito_do_Brasil_Arcade_Bootleg_v1.1_copperBottom.gbl, Taito_do_Brasil_Arcade_Bootleg_v1.1_copperTop.gtl, Taito_do_Brasil_Arcade_Bootleg_v1.1_maskBottom.gbs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]
2022-05-29 optimized configs for ESP32
2022-05-29 upraded to 1.2v
2022-05-29 Added actual board picture with captions
2022-05-30 minor fixing
    [Taito_do_Brasil_Arcade_Bootleg_v1.2_copperBottom.gbl, Taito_do_Brasil_Arcade_Bootleg_v1.2_copperTop.gtl, Taito_do_Brasil_Arcade_Bootleg_v1.2_maskBottom.gbs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]
2022-05-30 added PCB pictures
2022-05-30 added BOM
2022-05-30 added custom frame duration times
